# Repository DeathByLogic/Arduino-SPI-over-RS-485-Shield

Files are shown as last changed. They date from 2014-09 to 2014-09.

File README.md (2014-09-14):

Arduino-SPI-over-RS-485-Shield
==============================

An Arduino shield that converts the SPI signals from the Arduino to RS-485 for communications over long distances. If the distance is long enough to where the delay caused by the wire and transceivers causes the SPI communications to get out of sync there is a second SPI channel that can act as an slave device and receive the data back from the delayed SPI. There is also an LCD display and 5 button D-Pad for a control interface.

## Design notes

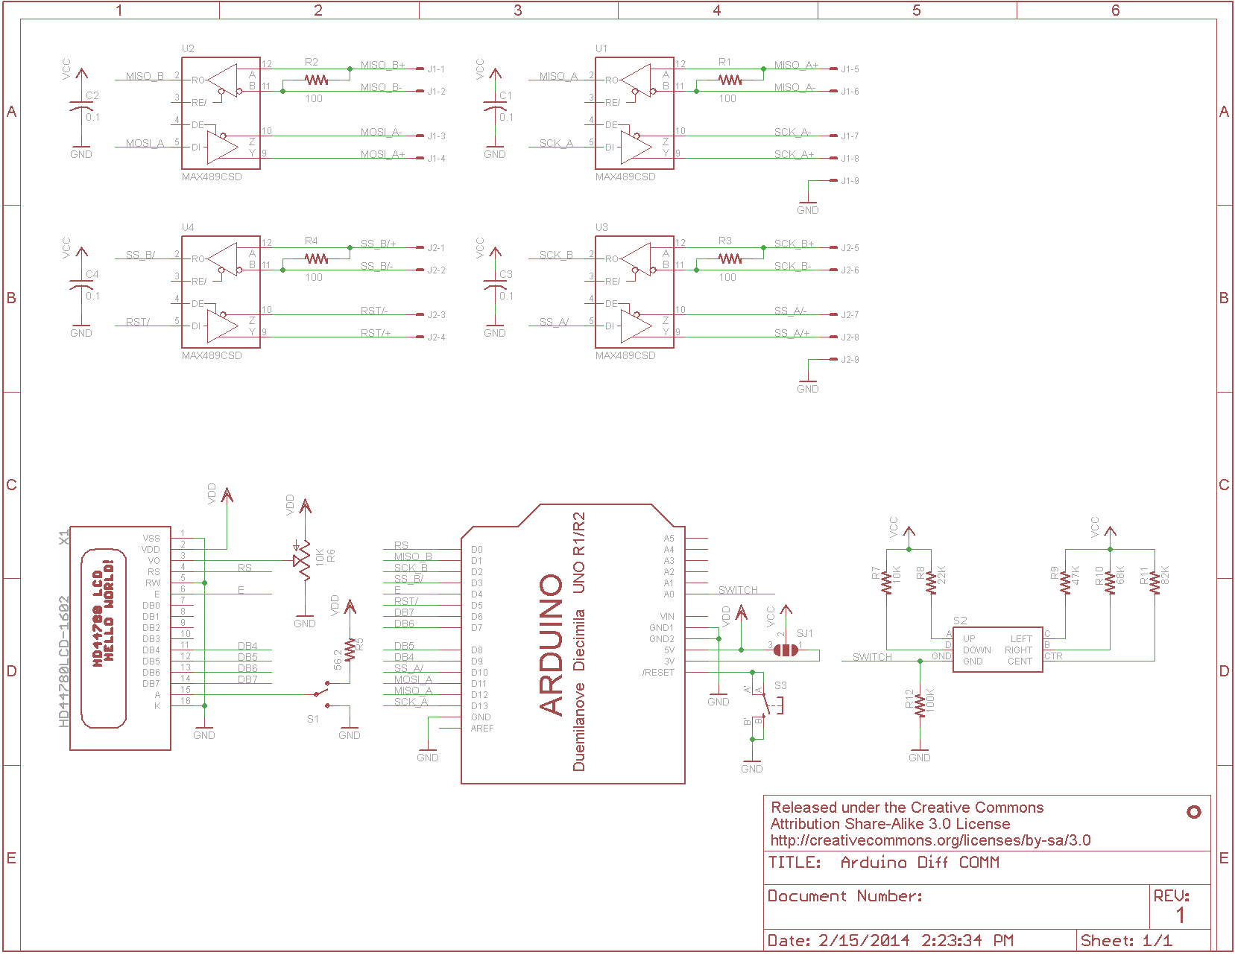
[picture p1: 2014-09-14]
Arduino DIFF COMM Schematic.png

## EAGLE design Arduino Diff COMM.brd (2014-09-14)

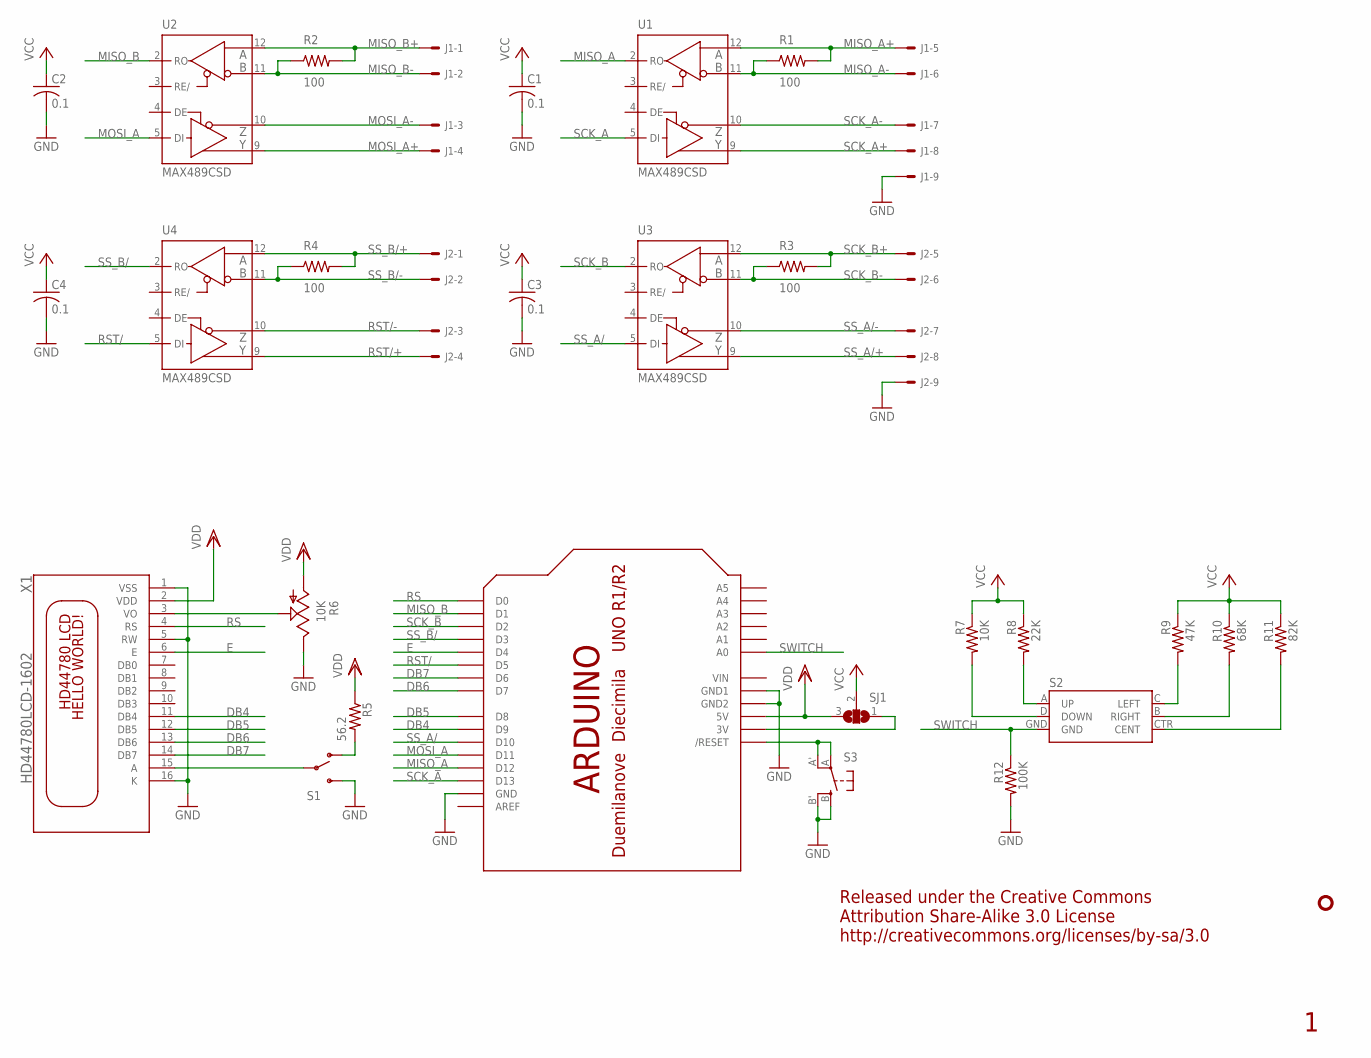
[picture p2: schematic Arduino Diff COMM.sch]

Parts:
C1, C2, C3, C4: 0.1; C0603K
J1, J2: 22-05-7098-09; 7395-09
R1, R2, R3, R4: 100; R1206
R5: 56.2; R0805
R6: 10K; 3223G
R7: 10K; R0805
R8: 22K; R0805
R9: 47K; R0805
R10: 68K; R0805
R11: 82K; R0805
R12: 100K; R0805
S1: SWITCH_SPDT; KPS-1290
S2: JOYSTICK_MINI
S3: SPST_TACT-EVQQ2; EVQ-Q2
SJ1: SJ2W; SJ_2
U1, U2, U3, U4: MAX489CSD; SO14
U$1: ARDUINO-NOHOLE
U$2: PENGUIN_LOGOCOPPER; PENGUIN_COPPER
X1: HD44780LCD-1602; LCD1602

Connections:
DB4: U$1.D9, X1.11 (DB4)
DB5: U$1.D8, X1.12 (DB5)
DB6: U$1.D7, X1.13 (DB6)
DB7: U$1.D6, X1.14 (DB7)
E: U$1.D4, X1.6 (E)
GND: C1.2, C2.2, C3.2, C4.2, J1.9, J2.9, R6.3 (E), R12.2, S1.S, S3.B (S), S3.B' (S1), U1.6 (GND), U1.7 (GND), U2.6 (GND), U2.7 (GND), U3.6 (GND), U3.7 (GND), U4.6 (GND), U4.7 (GND), U$1.GND, U$1.GND1, U$1.GND2, X1.1 (VSS), X1.5 (RW), X1.16 (K)
MISO_A: U1.2 (RO), U$1.D12
MISO_A+: J1.5, R1.2, U1.12 (A)
MISO_A-: J1.6, R1.1, U1.11 (B)
MISO_B: U2.2 (RO), U$1.D1
MISO_B+: J1.1, R2.2, U2.12 (A)
MISO_B-: J1.2, R2.1, U2.11 (B)
MOSI_A: U2.5 (DI), U$1.D11
MOSI_A+: J1.4, U2.9 (Y)
MOSI_A-: J1.3, U2.10 (Z)
unnamed: R5.2, S1.O
unnamed: R8.2, S2.A (UP)
unnamed: S1.P, X1.15 (A)
unnamed: R9.2, S2.C (LEFT)
unnamed: R11.2, S2.CTR (CENT)
unnamed: R10.2, S2.B (RIGHT)
unnamed: R7.2, S2.D (DOWN)
unnamed: R6.2 (S), X1.3 (VO)
unnamed: SJ1.1, U$1.3V
unnamed: S3.A, S3.A' (P1), U$1.RESET (/RESET)
RS: U$1.D0, X1.4 (RS)
RST/: U4.5 (DI), U$1.D5
RST/+: J2.4, U4.9 (Y)
RST/-: J2.3, U4.10 (Z)
SCK_A: U1.5 (DI), U$1.D13
SCK_A+: J1.8, U1.9 (Y)
SCK_A-: J1.7, U1.10 (Z)
SCK_B: U3.2 (RO), U$1.D2
SCK_B+: J2.5, R3.2, U3.12 (A)
SCK_B-: J2.6, R3.1, U3.11 (B)
SS_A/: U3.5 (DI), U$1.D10
SS_A/+: J2.8, U3.9 (Y)
SS_A/-: J2.7, U3.10 (Z)
SS_B/: U4.2 (RO), U$1.D3
SS_B/+: J2.1, R4.2, U4.12 (A)
SS_B/-: J2.2, R4.1, U4.11 (B)
SWITCH: R12.1, S2.GND, U$1.A0
VCC: C1.1, C2.1, C3.1, C4.1, R7.1, R8.1, R9.1, R10.1, R11.1, SJ1.2, U1.14 (VCC), U2.14 (VCC), U3.14 (VCC), U4.14 (VCC)
VDD: R5.1, R6.1 (A), SJ1.3, U$1.5V, X1.2 (VDD)
VIN: U$1.VIN

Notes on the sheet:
Released under the Creative Commons Attribution Share-Alike 3.0 License http://creativecommons.org/licenses/by-sa/3.0

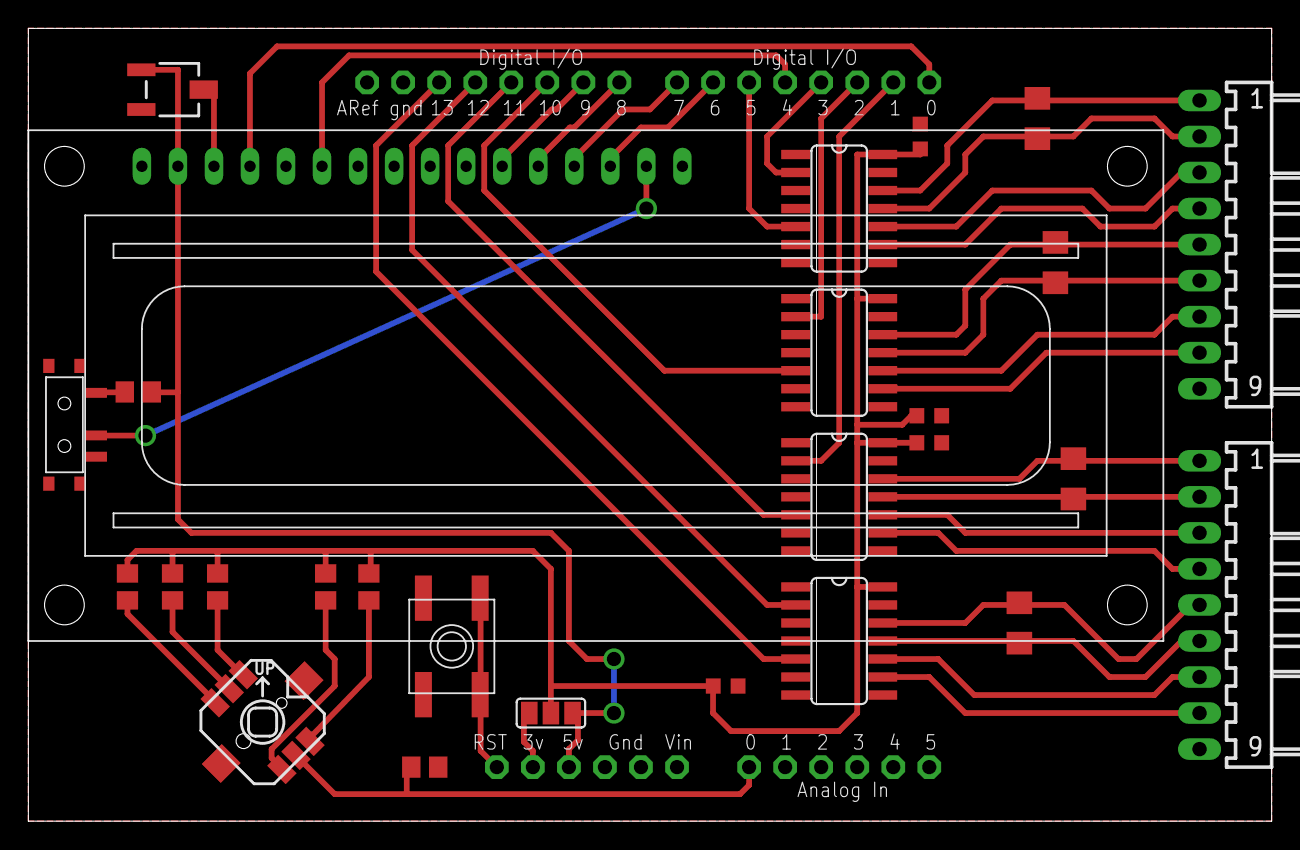
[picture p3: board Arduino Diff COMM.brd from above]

Board: 2 copper layers, 87.6 x 55.9 mm, 29 parts (0 on the bottom side), 44 nets.

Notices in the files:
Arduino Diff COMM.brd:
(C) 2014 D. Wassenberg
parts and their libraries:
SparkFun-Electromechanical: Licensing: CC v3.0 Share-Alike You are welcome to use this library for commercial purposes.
